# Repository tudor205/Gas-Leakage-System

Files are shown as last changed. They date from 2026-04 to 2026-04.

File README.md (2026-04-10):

# Gas-Leakage-System
A safety-critical embedded system capable of detecting hazardous gas concentrations and executing automated physical countermeasures (ventilation and window actuation).

Key Features & Modules:

 - Gas Sensing & Alarm: Integrated an MQ-series gas sensor with an Arduino-based logic controller to trigger real-time audio-visual alerts via an LCD 1602A and a Passive Buzzer.

 - Automated Actuation: Developed a window-control mechanism using a Driver and a Stepper Motor, complemented by a high-speed DC Motor for forced ventilation.

 - Remote Control & Safety: Implemented an Infrared (IR) control interface for manual system overriding and emergency stops.

 - Hardware Design: Engineered the full circuit schematics in KiCad, ensuring signal integrity and proper power distribution using PC817 Optocouplers for galvanic isolation between the logic and power stages.

Technical skills:

 - Hardware: Arduino, KiCad (PCB Design), Stepper & DC Motors, IR Sensors, Optocouplers.

 - Software: Embedded C++, Arduino IDE.





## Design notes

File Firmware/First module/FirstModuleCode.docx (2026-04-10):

AlarmaGaz.ino

#include <LiquidCrystal_I2C.h>

#include <Wire.h>

#include <IRremote.hpp>

#include <Stepper.h>

// initializare LCD

LiquidCrystal_I2C lcd(0x27, 16, 4);

#include "Wire.h"

#include "LiquidCrystal_I2C.h"

#include "Stepper.h"

#define STEPS 64 // Numar de pasi pentru o rotatie completa

const int pinImpuls = 2; // pin pentru generatorul de impulsuri dreptunghiulare NE555

// pini motoras DC

int mENA = 5; // PWM

int mIN1 = 3; // directie inainte

int mIN2 = 4; // directie inapoi

// pini pentru LED-urile IR (emițătoare) ---

int pinLedIR1 = 6;

int pinLedIR2 = 7;

// pini pentru motorasul pas cu pas

// In1, In2, In3, In4 in the secventa 1-3-2-4

const int mppIN1 = 11;

const int mppIN2 = 10;

const int mppIN3 = 9;

const int mppIN4 = 8;

const int recTelecomanda = 12; // pinul conectat la OUT de pe VS1838B

const int pinButonFereastra = 13; // pinul conectat la fereastra

int ultimaPozitieButon;

// Pin Alarma Gaz

int pinAlarmaGaz = A0;

// Pragul de detecție gaz. Daca este mai mare se declanseaza alarma

int pragSenzorGaz = 200; // 0-1023 (analog)

// --- Pini pentru fotodiode IR (receptoare) ---

int pinDiodaIR1 = A1;

int pinDiodaIR2 = A2;

// Pragul de intensitate a detectiei radiatiei in infrarosu

int pragDiodaIR = 100;

// Pin pentru a activare/dezactivare a placutei Arduino Uno 2 (GSM)

const int pinOptocuplor = A3;

int indexSample = 0;

bool bufferFull = false;

// Trimite jumatate de pas pentru 28BYJ-48

const int steps[8][4] = {

{ 1, 0, 0, 0 },

{ 1, 1, 0, 0 },

{ 0, 1, 0, 0 },

{ 0, 1, 1, 0 },

{ 0, 0, 1, 0 },

{ 0, 0, 1, 1 },

{ 0, 0, 0, 1 },

{ 1, 0, 0, 1 }

};

volatile bool cererePas = false;

int indexPas = 0;

int valDiodaIR1;

int valDiodaIR2;

// viteza motorului DC (poate lua valori intre 0..255)

int vitezaMotorDC = 100;

// temporizare pe intervale a activitatii senzorilor

unsigned long milisec1 = 0;

unsigned long milisec2 = 0;

unsigned long milisec3 = 0;

unsigned long milisec4 = 0;

const long intervalLEDTasta = 100; // interval pentru LED (in ms)

const long intervalSenzoriFereastra = 200; // interval pentru senzori fereastra (in ms)

const long intervalGaz = 300; // interval pentru detectie gaz (in ms)

const long intervalMotorDC = 500; // interval pentru motor DC (in ms)

volatile bool sistemActiv;

volatile bool alarmaGaz;

volatile bool ledNivel1;

volatile bool ledNivel2;

// ISR pentru impuls de la NE555

void pasISR() {

cererePas = true;

}

void setup() {

// activeaza afisarea mesajelor de Arduino

Serial.begin(9600);

// seteaza alarma de gaz

pinMode(pinAlarmaGaz, INPUT);

// seteaza buton fereastra

pinMode(pinButonFereastra, INPUT_PULLUP); // folosit ca intrare pentru buton fereastra

// seteaza optocuplor

pinMode(pinOptocuplor, OUTPUT);

// LED-uri IR

pinMode(pinLedIR1, OUTPUT);

pinMode(pinLedIR1, OUTPUT);

// LED-uri IR permanent active

digitalWrite(pinLedIR1, HIGH);

digitalWrite(pinLedIR2, HIGH);

// motoras pas cu pas

pinMode(mppIN1, OUTPUT);

pinMode(mppIN2, OUTPUT);

pinMode(mppIN3, OUTPUT);

pinMode(mppIN4, OUTPUT);

attachInterrupt(digitalPinToInterrupt(pinImpuls), pasISR, RISING);

// motoras DC

pinMode(mENA, OUTPUT);

pinMode(mIN1, OUTPUT);

pinMode(mIN2, OUTPUT);

digitalWrite(mIN1, LOW);

digitalWrite(mIN2, LOW);

analogWrite(mENA, 0);

// setare LCD

lcd.init();

lcd.backlight();

lcd.clear();

lcd.setCursor(0, 0);

lcd.print("1:");

lcd.setCursor(2, 0);

lcd.print("OFF");

sistemActiv = false;

alarmaGaz = false;

IrReceiver.begin(recTelecomanda, ENABLE_LED_FEEDBACK); // initializează receptorul

Serial.println("Verifica taste telecomanda");

}

void loop() {

// Arduino Uno nu suporta multi-threading

// citeste pozitia (inchis/deschis) butonului de fereastra

int pozitieButonFereastra = digitalRead(pinButonFereastra);

// citeste timpul curent al sistemului

unsigned long milisecCurent = millis();

// Simulare multi thread

if (milisecCurent - milisec1 >= intervalLEDTasta) {

milisec1 = milisecCurent;

VerificaTastaApasata();

}

if (sistemActiv) {

if (milisecCurent - milisec2 >= intervalGaz) {

milisec2 = milisecCurent;

VerificareSenzorGaz();

}

if (alarmaGaz) {

if (milisecCurent - milisec3 >= intervalSenzoriFereastra) {

milisec3 = milisecCurent;

VerificareSenzoriFereastra();

}

if (ledNivel2 == false) {

MotorPasInainte();

}

if (milisecCurent - milisec4 >= intervalMotorDC) {

milisec4 = milisecCurent;

if (pozitieButonFereastra == LOW) {

//Serial.println("Buton fereastra inchis.");

// opreste motoras DC

StopMotorDC();

// stop alarma pe a doua placa Arduino

StopOptocuplor();

ledNivel1 = false;

ledNivel2 = false;

} else {

//Serial.println("Buton fereastra deschis.");

if(ledNivel1 == true)

{

// mareste putin viteza dupa ce primul nivel de diode a fost depasit

vitezaMotorDC = 120;

}

if(ledNivel2 == true)

{

// mareste viteza la maxim dupa ce al doilea nivel de diode a fost depasit

vitezaMotorDC = 160;

}

// porneste motorul DC

StartMotorDC(vitezaMotorDC);

// motorasul pas cu pas - un pas inainte

//MotorPasInainte();

StartOptocuplor();

}

}

} else {

// opreste motoras DC

StopMotorDC();

// stop alarma pe a doua placa Arduino

StopOptocuplor();

}

} else {

if (pozitieButonFereastra == HIGH) {

MotorPasInapoi();

ultimaPozitieButon = pozitieButonFereastra;

}

if (ultimaPozitieButon != pozitieButonFereastra) {

//Serial.println("Fereastra inchisa!");

lcd.setCursor(9, 1);

lcd.print("Win: ");

lcd.setCursor(9, 1);

lcd.print("Win:");

lcd.print("I");

ultimaPozitieButon = pozitieButonFereastra;

}

}

}

void VerificaTastaApasata() {

// verifică dacă a fost recepționat un cod IR

if (IrReceiver.decode()) {

unsigned long code = IrReceiver.decodedIRData.decodedRawData;

//Serial.print("Codul: ");

//Serial.println(code);

lcd.setCursor(2, 0);

// corespondenta intre codurile de 32-bit reale si cifrele telecomenzii

switch (code) {

case 3125149440UL:

lcd.print(" ");

lcd.setCursor(2, 0);

lcd.print("ON");

sistemActiv = true;

Serial.println("1");

break; // cod buton 1

case 3108437760UL:

//lcd.print("2");

Serial.println("2");

break; // cod buton 2

case 3091726080UL:

//lcd.print("3");

Serial.println("3");

break; // cod buton 3 (exemplu, verifică)

case 3141861120UL:

//lcd.print("4");

Serial.println("4");

break; // cod buton 4

case 3208707840UL:

//lcd.print("5");

Serial.println("5");

break; // cod buton 5

case 3158572800UL:

//lcd.print("6");

Serial.println("6");

break; // cod buton 6

case 4161273600UL:

//lcd.print("7");

Serial.println("7");

break; // cod buton 7

case 3927310080UL:

//lcd.print("8");

Serial.println("8");

break; // cod buton 8

case 4127850240UL:

//lcd.print("9");

Serial.println("9");

break; // cod buton 9

case 3860463360UL:

lcd.print(" ");

lcd.setCursor(2, 0);

lcd.print("OFF");

sistemActiv = false;

OpresteSistemAlarma();

Serial.println("0");

break; // cod buton 0

default:

Serial.println("Alt buton");

break;

}

IrReceiver.resume(); // asteapta un semnal nou

}

}

void VerificareSenzorGaz() {

lcd.setCursor(0, 1);

int valSenzorGaz = analogRead(pinAlarmaGaz);

lcd.print("Gaz: ");

lcd.setCursor(0, 1);

lcd.print("Gaz:");

lcd.print(valSenzorGaz);

if (valSenzorGaz >= pragSenzorGaz) {

lcd.print("+"); // valorile de gaz sunt peste prag (pericol)

alarmaGaz = true;

} else {

lcd.print("-"); // valorile de gaz sunt sub prag (normal)

alarmaGaz = false;

}

}

void VerificareSenzoriFereastra() {

// Citește fotodiodele

valDiodaIR1 = analogRead(pinDiodaIR1);

valDiodaIR2 = analogRead(pinDiodaIR2);

if (valDiodaIR1 > pragDiodaIR || valDiodaIR2 > pragDiodaIR) {

// Afișare valori citite de la diode (pentru a vedea daca senzorii de fereastra sunt centrati si comunica intre ei)

Serial.print("R1: ");

Serial.print(valDiodaIR1);

Serial.print(" | R2: ");

Serial.print(valDiodaIR2);

Serial.print(" | Nivel1: ");

Serial.print(ledNivel1);

Serial.print(" | Nivel2: ");

Serial.print(ledNivel2);

Serial.print(" | Ultima pozitie buton: ");

Serial.println(ultimaPozitieButon);

}

lcd.setCursor(9, 1);

lcd.print("Win: ");

lcd.setCursor(9, 1);

lcd.print("Win:");

if (valDiodaIR1 > pragDiodaIR) {

ledNivel1 = true;

}

if (valDiodaIR2 > pragDiodaIR) {

ledNivel2 = true;

}

// === Detectare fascicul IR ntrerupt ===

if (ledNivel1 == false && ledNivel2 == false) {

//Serial.println("Fereastra inchisa!");

lcd.print("I");

} else if (ledNivel1 == true && ledNivel2 == false) {

//Serial.println("Fereastra deschisa!");

lcd.print("D");

} else if (ledNivel1 == true && ledNivel2 == true) {

//Serial.println("Fereastra complet deschisa!");

lcd.print("CD");

} else {

// senzorii IR sunt dereglati

lcd.print(ledNivel1);

lcd.print(ledNivel2);

}

}

// porneste motorasul DC

void StartMotorDC(int viteza) {

// Serial.print("Motor DC pornit");

lcd.setCursor(8, 0);

lcd.print("VEN1: ");

lcd.setCursor(8, 0);

lcd.print("VEN1:ON");

// motor DC inainte

digitalWrite(mIN1, HIGH);

digitalWrite(mIN2, LOW);

analogWrite(mENA, viteza);

delay(10);

}

// opreste motorasul DC

void StopMotorDC() {

// Serial.print("Motor DC oprit");

lcd.setCursor(8, 0);

lcd.print("VEN1: ");

lcd.setCursor(8, 0);

lcd.print("VEN1:OFF");

if (vitezaMotorDC != 0) {

vitezaMotorDC = 0;

analogWrite(mENA, vitezaMotorDC);

delay(10);

}

}

// Motoras pas cu pas - un pas inainte

void MotorPasInainte() {

MotorPasCuPasInDirectia(-1);

}

// Motoras pas cu pas - un pas inapoi

void MotorPasInapoi() {

MotorPasCuPasInDirectia(1);

}

// Motoras pas cu pas - in directia

void MotorPasCuPasInDirectia(int directie) {

if (cererePas) {

cererePas = false;

// Facem 2 semipasi (1 pas motor) pentru un impuls NE555 (pentru a deschide mai repede fereastra)

for (int i = 0; i < 2; i++) {

// Aplică pasul curent

digitalWrite(mppIN1, steps[indexPas][0]);

digitalWrite(mppIN2, steps[indexPas][1]);

digitalWrite(mppIN3, steps[indexPas][2]);

digitalWrite(mppIN4, steps[indexPas][3]);

// Schimbă indexul în funcție de direcție

indexPas = (indexPas + directie + 8) % 8;

delay(2); // mic delay pentru stabilitate

}

}

}

void StartOptocuplor() {

// activeaza a doua placuta Arduino

digitalWrite(pinOptocuplor, HIGH);

delay(20);

}

void StopOptocuplor() {

// dezactiveaza a doua placa Arduino

digitalWrite(pinOptocuplor, LOW);

delay(20);

}

void OpresteSistemAlarma() {

StopMotorDC();

StopOptocuplor();

}

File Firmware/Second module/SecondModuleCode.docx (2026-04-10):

ArduinoGSM.ino

#include <LiquidCrystal_I2C.h>

#include <Wire.h>

#include <SoftwareSerial.h>

#include "Wire.h"

#include "LiquidCrystal_I2C.h"

LiquidCrystal_I2C lcd(0x27, 16, 4);

const int pinOptoReleu = 5;

const int pinOptocuplor = 6;

const int pinBistabil = 7;

const int pinSunetAlarma = 12;

// RX și TX conectate la modul SIM800L

SoftwareSerial sim800(10, 11); // RX, TX

int wait = 0;

int Do = 262, Re = 294, Mi = 330, Fa = 349, Sol = 392,

La = 440, Si = 494, Do2 = 524;

unsigned long milisec1 = 0;

unsigned long milisec2 = 0;

unsigned long milisec3 = 0;

unsigned long milisec4 = 0;

const long intervalReadOctocuplor = 100; // interval pentru citire optocuplor (in ms)

const long intervalLumini = 200; // interval pentru activare vizuala (in ms)

const long intervalSunet = 300; // interval pentru activare sonora (in ms)

const long intervalSMS = 30000; // interval pentru trimitere SMS (in ms)

void setup() {

Serial.begin(9600); // viteza pentru PC

sim800.begin(9600); // viteza SIM800L

pinMode(pinOptoReleu, OUTPUT);

digitalWrite(pinOptoReleu, LOW); // motorul OPRIT la pornire

pinMode(pinOptocuplor, INPUT);

pinMode(pinBistabil, OUTPUT);

digitalWrite(pinBistabil, LOW);

pinMode(pinSunetAlarma, OUTPUT);

lcd.init();

lcd.backlight();

lcd.clear();

lcd.setCursor(0, 0);

lcd.print("2:");

}

void loop() {

int valOptocuplor = digitalRead(pinOptocuplor);

unsigned long milisecCurent = millis();

// Simulare multi thread

if (milisecCurent - milisec1 >= intervalReadOctocuplor) {

milisec1 = milisecCurent;

AfiseazaStareOctocuplor(valOptocuplor);

}

if (milisecCurent - milisec2 >= intervalSunet) {

milisec2 = milisecCurent;

ActiveazaSunet(valOptocuplor);

}

if (milisecCurent - milisec3 >= intervalLumini) {

milisec3 = milisecCurent;

ComutaBistabili(valOptocuplor);

}

ActiveazaOptoReleu(valOptocuplor);

if (milisecCurent - milisec4 >= intervalSMS) {

milisec4 = milisecCurent;

TrimiteSMS(valOptocuplor);

}

}

void AfiseazaStareOctocuplor(int valoareOctocuplor) {

lcd.setCursor(2, 0);

lcd.print(" ");

lcd.setCursor(2, 0);

if (valoareOctocuplor == LOW) {

lcd.print("ON");

} else {

lcd.print("OFF");

}

delay(200);

}

void ComutaBistabili(int valoareOctocuplor) {

lcd.setCursor(8, 0);

lcd.print("LEDS: ");

lcd.setCursor(8, 0);

lcd.print("LEDS:");

if (valoareOctocuplor == LOW) {

lcd.print("ON");

// Impuls pentru comutare

digitalWrite(pinBistabil, HIGH);

delay(100); // impuls scurt

digitalWrite(pinBistabil, LOW);

delay(100); // pauză între comutări

} else {

lcd.print("OFF");

}

}

void ActiveazaSunet(int valoareOctocuplor) {

if (valoareOctocuplor == LOW) {

wait = 200;

tone(pinSunetAlarma, Sol, wait);

delay(200);

tone(pinSunetAlarma, Re, wait);

delay(200);

tone(pinSunetAlarma, Fa, wait);

delay(200);

wait = 500;

tone(pinSunetAlarma, Sol, wait);

delay(500);

} else {

noTone(pinSunetAlarma);

}

delay(100);

}

void TrimiteSMS(int valoareOctocuplor) {

lcd.setCursor(0, 1);

lcd.print("SMS: ");

lcd.setCursor(0, 1);

lcd.print("SMS:");

// Serial.println("=== Test functionalitate pentru modulul GSM SIM800L V2.0 ===");

// delay(1000); // asteaptapentru inițializare

// TrimiteComenziGSM("AT"); // test comunicare

// TrimiteComenziGSM("AT+GMR"); // versiune firmware

// TrimiteComenziGSM("AT+CPIN?"); // status SIM

// TrimiteComenziGSM("AT+CSQ"); // semnal GSM

// TrimiteComenziGSM("AT+CREG?"); // inregistrare in retea

// TrimiteComenziGSM("AT+CBC"); // alimentare / baterie

if (valoareOctocuplor == LOW) {

// trimite SMS la telefonul

TrimiteComenziGSM("AT"); // test comunicare

TrimiteComenziGSM("AT+CSQ"); // semnal GSM

TrimiteComenziGSM("AT+CREG?"); // inregistrare in retea

TrimiteComenziGSM("AT+CMGF=1"); // spcifica mesajul in mod text

sim800.print("AT+CMGS=\"0787674842\"\r"); // numarul de telefon

sim800.println("Alarma Gaz."); // mesajul SMS

delay(300);

sim800.write(26); // 26 = CTRL+Z, se trimite mesajul

lcd.print("ON"); // SMS-ul a fost trimis

} else {

lcd.print("OFF");

}

delay(500);

}

void ActiveazaOptoReleu(int valoareOctocuplor) {

lcd.setCursor(8, 1);

lcd.print("VEN2: ");

lcd.setCursor(8, 1);

lcd.print("VEN2:");

if (valoareOctocuplor == LOW) {

// Activeaza al doilea ventilator

digitalWrite(pinOptoReleu, LOW);

lcd.print("ON");

} else {

digitalWrite(pinOptoReleu, HIGH);

lcd.print("OFF");

}

delay(500);

}

void TrimiteComenziGSM(String cmd) {

sim800.println(cmd);

delay(500);

while (sim800.available()) {

Serial.write(sim800.read());

}

}

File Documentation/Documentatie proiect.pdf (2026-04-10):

NEAMȚU ANDREI TUDOR | GRUPA 30229

# SISTEM DE ALARMARE

# SI PROTECTIE IN CAZUL SCURGERILOR DE GAZE

## CUPRINS

## LISTA DE ABREVIERI SI SIMBOLURI

Simbol | Unitare de masura | Comentariu
V | Volti | Diferenta de potential (tensiune electrica)
mV | Milivolti
A | Amperi | Intensitatea curentului electric
mA | Miliamperi
Ω | Ohmi | Rezistenta electrica
m Ω | Miliohmi
nm | nanometri | lungimea de unda a unei fotodiode in infrarosu
DC | - | curent continuu
AC | - | curent alternativ
MPP | Motoras pas cu pas
MDC | Motoras DC la 6V
RF | unde radio frecventa
IR | Unde infrarosu

## INTRODUCERE

In zilele noastre observam destul de frecvent ca au loc accidente datorate scurgerilor accidentale de gaz care au consecinte grave fizice si materiale pentru cetateni, comunitate si domeniul industrial.

Desi exista norme si normative care aplicate evita astfel de accidente, acestea continua sa aiba loc. Desi existenta senzorilor de gaz odata activati opresc emisia de gaz, pare sa fie doar primul pas necesar pentru evitarea consecintei acumularii excesive de gaz intr-un spatiu inchis. Daca mai luam in calcul ca de multe ori acesti senzori de gaz au iesit din perioada de garantie, tragem concluzia ca mai trebuie adaugat inca un pas.

Proiectul propune o solutie complementara la senzorii de gaz existenti deja in locuinte, hale industriale, birouri si magazine, et cetera si anume adaugarea unui sistem de gestionare a evacuarii gazului acumulat dintr-o incinta dupa ce senzorul de gaz a blocat de la contor furnizarea de gaz.

## DESCRIEREA REALIZARII PRACTICE

I. GESTIUNE DESCHIDERE-INCHIDERE FEREASTRA (PRIMUL MODUL)

Pentru acest modul se foloseste

Un adaptor de tensiune 9V / 3A care alimenteaza:
- primul breadboard in care se include primul adaptor(sursa) de tensiune DC (de la 9V la 5V, 700 mA – breadboard power supply)
- prima placuta Arduino UNO (pentru senzorii de alarma gaz)
- primul afisaj LCD1602A folosind adaptorul I2C pentru monitorizarea componentelor din circuit
LCD1602A – I2C | Arduino
VCC | +5V
GND | GND
SDA | A4
SCL | A5

SDA (Serial Data)
SCL (Serial Clock)

la care se leaga urmatorii senzori (traductori) dupa cum urmeaza:
1. Detectie prezenta gaz

Pentru acest pas se foloseste un sensor de gaz MQ2

Observatie: Inainte de folosire acest sensor MQ2 se pre-incalzeste intre 24-48 de ore, dupa care raporteaza corect valorile detectate.

Legaturile intre senzorul de gaz sunt pe breadboard si plauta Arduino sunt:

MQ2 | Breadboard

VCC | +5V
GND | GND
AOUT | A0
DOUT | nefolosit
2. Pornire si inchidere sistem cu telecomanda

Pentru a receptiona semnalele de telecomanda se foloseste un fototranzistor in infrarosu (infrared receiver module - VS1838B). Acesta receptioneaza semnalele de ~38 KHZ de la o telecomanda Arduino.

VS1838B | Breadboard
VCC | +5V
GND | GND
VOUT | D 12
3. Buton de control deschidere fereastra

Butonul se leaga simplu de la fereastra direct la placa Arduino

Buton cu revenire (incastrat in fereastra) | Arduino
Pin 1 | D13
Pin 2 | GND
4. Senzori cu monitorizare la deschiderea fereastrei

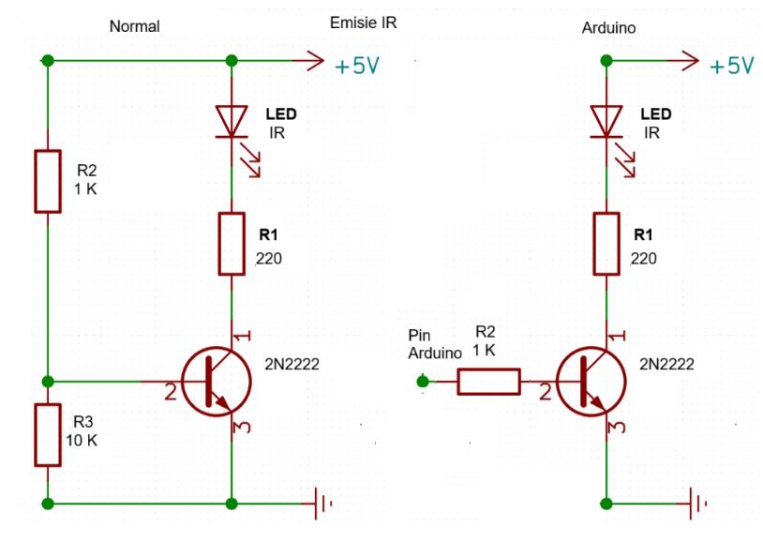
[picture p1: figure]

Cand pe pinul Arduino se seteaza HIGH, pe baza exista o tensiune, tranzistorul intra in comutatie (conduce) iar LED-ul IR emite radiatie in infrarosu. hFE = Ic/IB (factorul de amplificare) pentru 2N2222 este 280 care se incadreaza in domeniul de functionare 70-300.

Cand pe pinul Arduino se seteaza LOW, pe baza exista un current mic care face ca tranzistorul sa intre in blocare (nu mai conduce) iar prin dioda IR nu mai trece current si nu mai emite.

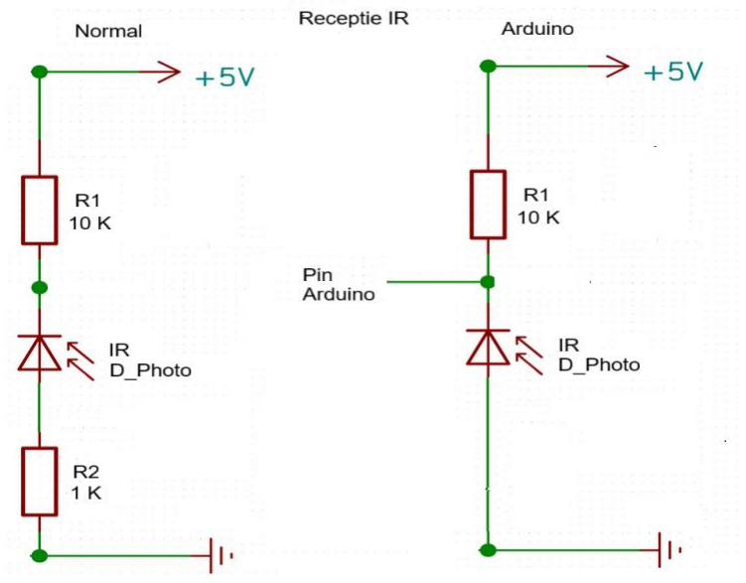
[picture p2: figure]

Cand pe dioda IR se receptioneaza radiatie in infrarosu aceasta conduce si pe pinul Arduino se obtine (citeste) LOW.
Cand pe dioda IR nu se receptioneaza radiatie aceasta nu conduce si pe pinul Arduino se obtine (citeste) aproape 5V HIGH.

In acest sistem s-au introdus 2 diode IR LED si 2 diode IR Photo. Prima pereche sesizeaza dupa ce butonul de deschidere a fost deschis daca fereastra s-a deplasat pana in dreptul primei perechi si valideaza primul prag al deschiderii ferestrei, dupa care urmeaza a doua pereche care sesizeaza depasirea celui de-al doilea prag ceea ce e semn ca motorasul pas cu pas inceteaza deplasarea (fereastra nu se deschide mai departe). In sens invers atunci cand gazul este evacuat si senzorul de gaz este sub pragul de detectie gaz fereastra revine in pozitia initiala, adica se inchide fiind monitorizate de senzorii de infrarosu in sens invers, motorasul oprindu-se dupa ce butonasul de fereastra s-a inchis.

Senzori IR pe breadboard | Arduino
LED IR 1 (baza tranzistor + 1kΩ) | D6
LED IR 2 (baza tranzistor + 1 kΩ) | D7
Dioda IR 1 (catod fotodioda) | A1
Dioda IR 2 (catod fotodioda) | A2
5. Evacuare gaz - deschidere fereastra

Pentru acest pas se folosete un generator de impulsuri dreptunghiulare (NE555) si un motor pas cu pas 28BYJ-48 coordonat de un controler ULN2003A. Impulsurile de la NE555 se trimit prin D2 catre ULN

Legaturi

NE555 | Arduino
VCC | +5V
GND | GND
OUT | D2
ULN2003A | Arduino
VCC | +5V
GND | GND
IN1 | D11

IN2 | D10
IN3 | D9
IN4 | D8

Scenariul pornirii si opririi motorasului pas cu pas este conform descrierii de la punctul 4.
6. Evacuare gaz – pornire ventilator

Pentru acest pas se foloseste un driver de motor si un motoras DC (5 – 9V)

Acest circuit evacueaza (complementar cu fereastra) gaz-ul in exces existent din incinta printr-o gaura speciala din perete spre exterior, accelerand astfel procesul de evacuare.
a) Deoarece motorasul alimentat la 6V consuma un current in jur de 2A se foloseste urmatorul driver de motor (L298N Dual H-Bridge Motor Driver) care poate conduce motorase care consuma pana la 10 A.

Pentru montaj in Arduino de pe placuta de driver jumper-ul ENA a fost scos pentru a suporta inversarea de directie. Urmatorii pini digitali au fost setati pe placuta de Arduino:

Driver-ul de motoras DC | Breadboard + adaptor + motor DC
Pin 5 | ENA
Pin 3 | IN1 (directie inainte)
Pin 4 | IN2 (directie inapoi)
OUT1 | + motor DC
OUT2 | - motor DC
+12V | + alimentator extern de 9V
GND | - alimentator extern de 9V

Bornele driver-ului nu s-au legat la breadboard-ul alimentat de la aceeasi adaptor extern. Mini-adaptorul de DC (9V – 5V) nu furnizeaza destul curent pentru ca motorasul care lucreaza normal la tensiunea nominala de +6V pana la +9V, sub 6V rotindu-se circa 30 secunde si intrand in protectie de curent insuficient.

b) Motorasul - este din kit-ul Arduino si este considerat din categoria (130 size) care inseamna ca se roteste continuu (cu o viteza constanta) mai repede sau mai incet in functie de viteza setata din cod pe pinul 5 din Arduino care accepta o valoare intre 0-255 (viteza minima-viteza maxima). Cu cat aceasta valoare e mai mare cu atat consumul de curent e mai mare fiind direct proportional cu viteza de rotatie.
7. Activare notificari auxiliare - modulul 2

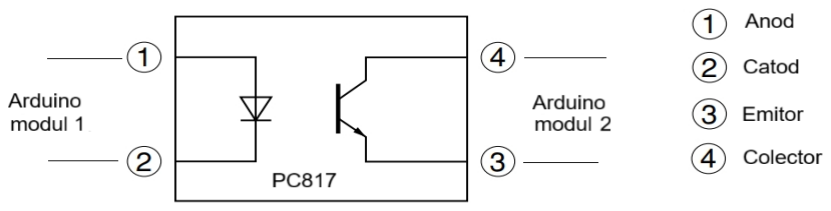
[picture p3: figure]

Optocuplor PC817 (intrare) | Arduino
Pin 1 | A3
Pin 2 | GND
II. | GESTIUNE DE NOTIFICARI AUXILIARE (AL DOILEA MODUL)

Si pentru acest modul se folosesc legaturile ca si mai sus

Un adaptor de tensiune 9V / 3A care alimenteaza:
- Al doilea breadboard in care se include un al doilea adaptor de tensiune DC (de la 9V la 5V, 700 mA– breadboard power supply)
- a doua placuta Arduino UNO
- al doilea afisaj LCD1602A folosind adaptorul I2C pentru monitorizarea componentelor din circuit

Legaturi

LCD1602A – I2C | Arduino
VCC | +5V
GND | GND
SDA | A4

SCL | A5

la care se leaga urmatorii senzori (traductori) dupa cum urmeaza:
8. Receptionare alarma de la modulul 1

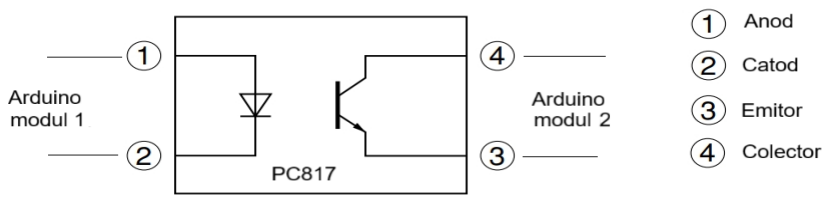
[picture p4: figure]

Optocuplor PC817 (iesire) | Breadboard
Pin 4 | D6
Pin 3 | GND
9. Alarmare vizuala

Pentru acest pas o sa folosim un circuit bistabil RS classic care va tranzita dintr-o stare in alta cu ajutorul unor stari de comutatie date de un pin Arduino

Legaturi

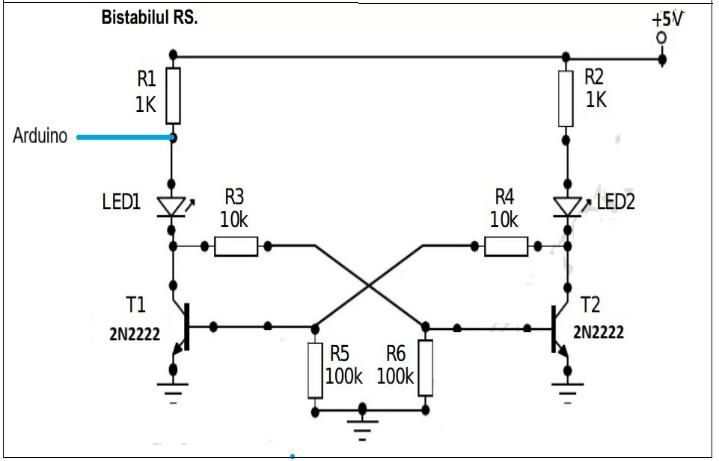
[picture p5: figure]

Circuit Bistabil cu 2 diode LED-uri ce emit in spectrul vizibil (Breadboard)

Arduino

+5V | +5V
GND | GND
Anod LED1 | D7
10. Alarmare Sonora

Se foloseste un buzzer pasiv care se leaga la placa Arduino

Buzzer pasiv | Arduino
borna + | D12
borna - | GND
11. Trimitere mesaj alarma GSM

Pentru a trimite mesaje de atentionare pe telefon s-a adaugat un modul specializat (modul SIM800L V2.0). Acesta are alimentare la +5V si poate fi folosit de Arduino in banda de emisie 2G care este inca acoperita de operatorul DIGI. Se foloseste o cartela pre-pay care se introduce in modul si restul se rezolva prin comunicatia GSM.

Legaturi

Modul SIM800L V2.0 | Breadboard
RX | D11
TX | D10
+5V | +5V
GND | GND

Arduino

GND | GND1
12. Activare motoras auxiliar pentru evacuare gaz

In cazul in care evacuarea este urgenta se poate extinde solutia printr-un optoreleu. In acest proiect s-a adaugat un optoreleu cu 2 canale. Circuitul de intrare al optoreleului este proiectat pentru +5V (DC) si curenti mici, iar iesirea este un releu proiectat pentru un circuite in current alternativ 220V/10A sau curent continuu cu DC 30V/10A.
Avantajul este dat de separerea circuitelor cu ajutorul optoreleului. Ca si exemplu am folosit iesirea de releu pentru a alimenta intr-un circuit auxiliar un motoras la +5V dar se poate adauga orice alt fel de circuit auxiliar ce poate ajuta la evacuarea rapida a gazului sau alte scenarii de rezolvare a alarmelor de acest fel.

Legaturi

Modul OptoReleu | Breadboard
DC+ | +5V
DC- | GND
COM1 | +5V
NO1 | +5V motor DC
NC1 | nefolosit
| Arduino
IN1 | D5

## CONCLUZII

In zilele noastre observam ca incidenta accidentelor datorate scurgerilor de gaz ramane inca ridicata iar consecintele datorate acestor evenimente au un implicatii umane si materiale de multe ori majore. Costurile cu remedierea acestor distrugeri cresc foarte mult atat in plan social ca spitalizare, recuperare medicala cat si economic care implica refacerea infrastructurii asa cum exista inainte de incident.

Astfel existenta unui sistem complementar la cel existent, cum ar fi evacuarea gazelor acumulate in exces, ar putea evita si reduce pierderile umane si materiale, reducand costurile economice in acest caz. Costurile pentru implementarea unei astfel de solutii, de eliminare a gazelor in exces, sunt mult mai mici prin comparatie cu cel al daunelor.

Partea mecanica a acestui proiect este o improvizatie, bazata pe compunerea fortei elastice a arculetului si gravitatia datorata contragreutatiilor legate de ferestra. Exista deja pe piata mecanisme cu lanturi si arcuri care pot deschide o fereastra in mod controlat intr-un mod mult mai profesionist. Avantajul este oferit insa in schimb de gestiunea datorata de senzorii care ajuta la evacuarea accelerata a gazelor acumulate in exces.

## BIBLIOGRAFIE

Libraria Arduino ( versiunea 2.3.6 ) – Datasheets (in format PDF) pentru componentele folosite

- UNO.pdf
- Breadboard MB-102.pdf
- Breadboard Power Supply.pdf
- LCD1602A.pdf
- MQ2.pdf
- VS1838B.pdf
- PN2222.pdf
- NE555.pdf (NE555_SA555_NA555.pdf)
- 28BYJ-48 Stepper Motor.pdf
- ULN2003A.pdf
- L298N Motor Driver manual.pdf
- 130 DC Motor.pdf
- PC817.pdf
- Passive buzzer.pdf

Site Arduino
https://www.arduino.cc/

Link Arduino – forum https://forum.arduino.cc

https://projecthub.arduino.cc/

Afisaj LCD1602A
https://www.scribd.com/document/740211847/Descriere-conectare-LCD

VS1838B
https://www.kasuo.com/product/vs1838b-arduino-ir-receiver/

Circuite LED IR, Dioda ID

https://www.instructables.com/Intro-to-IR-Circuits/

NE555
https://www.diodes.com/assets/Datasheets/NE555_SA555_NA555.pdf

ULN2003A

https://www.ti.com/lit/ds/symlink/uln2003a.pdf

https://www.diodes.com/assets/Datasheets/ULN2003V12_ULN2003F12.pdf

Optocuplor (4xPC817)

https://www.alldatasheet.com/datasheet-pdf/download/43368/SHARP/PC817.html

https://global.sharp/products/device/lineup/data/pdf/datasheet/PC817XxNSZ1B_e.pdfhttps://datasheet.octopart.com/PC817-Sharp-Microelectronics-datasheet-101325.pdf

Proiectare scheme de circuit kiCAD ( versiunea 9.0.6 )

Ssimboluri si footprint-uri care nu exista deja in librarie

VS1838B

https://github.com/andres-garcia-alves/electronics-kicad-custom-simbols

ULN2003A

https://www.digikey.com.au/en/models/5054226?tab=ultralibrarian

https://github.com/kitspace/kicad_footprints

MQ2

https://github.com/CGrassin/kicad_parts

https://www.winsen-sensor.com/d/files/semiconductor/mq-2.pdf

Sursa alimentare pentru breadboard

https://github.com/Ikarthikmb/Circuit-Designs

LCD 1602A

https://github.com/nosuz/kicad-symbols-footprints

Componentele pentru proiect au fost achizitionate de la: eMAG, SIGMANORTEC, Hornbach, Dedeman.
